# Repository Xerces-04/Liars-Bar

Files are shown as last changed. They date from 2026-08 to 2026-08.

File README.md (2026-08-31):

# Liar's Bar: Tabletop Hardware Edition

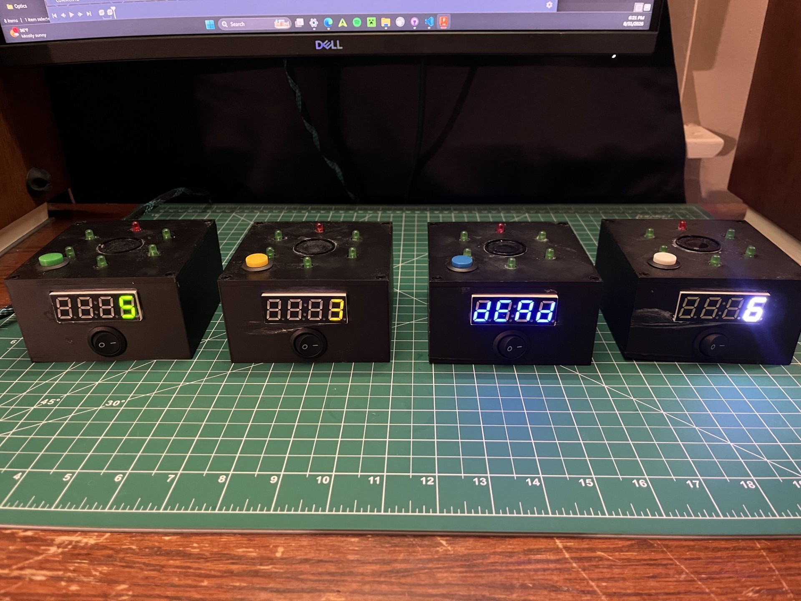
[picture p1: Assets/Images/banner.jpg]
Project Banner


An interactive, embedded implementation of the *Liar's Bar* revolver / Russian Roulette game mechanic built on Arduino. The project features randomized chamber states, dynamic LED indicator animations, synchronized audio cues via a DFPlayer Mini, real-time life tracking on a 7-segment display, and a dedicated 3D-printable square enclosure with heat-set threaded inserts.

---

## Features

* **True-Random Cylinder Spin:** Seeds pseudo-random generation using floating analog noise on pin `A0` combined with a Fisher-Yates array shuffle.
* **Synchronized Audio System:** Multi-channel sound effects driven by the DFPlayer Mini:
  * Cylinder spinning & cocking on startup/reload
  * Hammer cock on trigger pull
  * Dry fire click on safe rounds
  * Gunshot on live rounds
* **Visual Status Indicators:**
  * **TM1637 4-Digit Display:** Tracks remaining chamber counts (`6` down to `1`) and displays a custom `dEAd` segment pattern on elimination.
  * **6-LED Array:** 5 Green LEDs (safe chambers) and 1 Red LED (lethal chamber) with dynamic spinning deceleration sequences.
* **Rugged Enclosure Design:** Two-part square enclosure (base + lid) joined via four M3 heat-set brass inserts, featuring front-facing power and status readouts and top-mounted player controls.

---

## System Architecture & Pinout

```
                           +-------------------+
                           |    Arduino Uno/   |
                           |    Nano (MCU)     |
                           +---------+---------+
                                     |
      +---------------+--------------+--------------+---------------+
      |               |              |              |               |
+-----+-----+   +-----+-----+  +-----+-----+  +-----+-----+   +-----+-----+
|  TM1637   |   | DFPlayer  |  | 6x LED    |  | Fire      |   | Power     |
| 7-Segment |   |   Mini    |  | Array     |  | Pushbutton|   | Rocker    |
| (CLK/DIO) |   | (Software |  | (5G / 1R) |  | (Pullup)  |   | Switch    |
|           |   |  Serial)  |  |           |  |           |   |           |
+-----------+   +-----------+  +-----------+  +-----------+   +-----------+
```

### Pin Assignment Table

| Arduino Pin | Connected Hardware | Signal / Mode | Description |
| :--- | :--- | :--- | :--- |
| **D2** | Green LED 1 (`G1`) | `OUTPUT` | Safe Chamber 1 Indicator |
| **D3** | Green LED 2 (`G2`) | `OUTPUT` | Safe Chamber 2 Indicator |
| **D4** | Green LED 3 (`G3`) | `OUTPUT` | Safe Chamber 3 Indicator |
| **D5** | Green LED 4 (`G4`) | `OUTPUT` | Safe Chamber 4 Indicator |
| **D6** | Green LED 5 (`G5`) | `OUTPUT` | Safe Chamber 5 Indicator |
| **D7** | Red LED 1 (`R1`) | `OUTPUT` | Lethal Chamber Indicator |
| **D8** | TM1637 Display | `OUTPUT` | Display Clock (`CLK`) |
| **D9** | Push Button | `INPUT_PULLUP`| Fire / Trigger / Reset Action |
| **D10** | TM1637 Display | `OUTPUT` | Display Data I/O (`DIO`) |
| **D11** | DFPlayer Mini `RX` | `OUTPUT` (SoftSerial) | Arduino TX → DFPlayer RX (via 1kΩ resistor) |
| **D12** | DFPlayer Mini `TX` | `INPUT` (SoftSerial) | Arduino RX ← DFPlayer TX |
| **A0** | *Unconnected* | `INPUT` | Floating ADC input for random entropy |
| **A1** | DFPlayer Mini `BUSY`| `INPUT` | Audio playback status monitoring |

---

## Custom PCB Design

A custom carrier PCB was designed in KiCad/EasyEDA to eliminate messy point-to-point breadboard wiring, consolidate the pullups and current-limiting resistors, and fit snugly inside the 3D-printed enclosure.

| Schematic View | 3D Board Render |
| :---: | :---: |
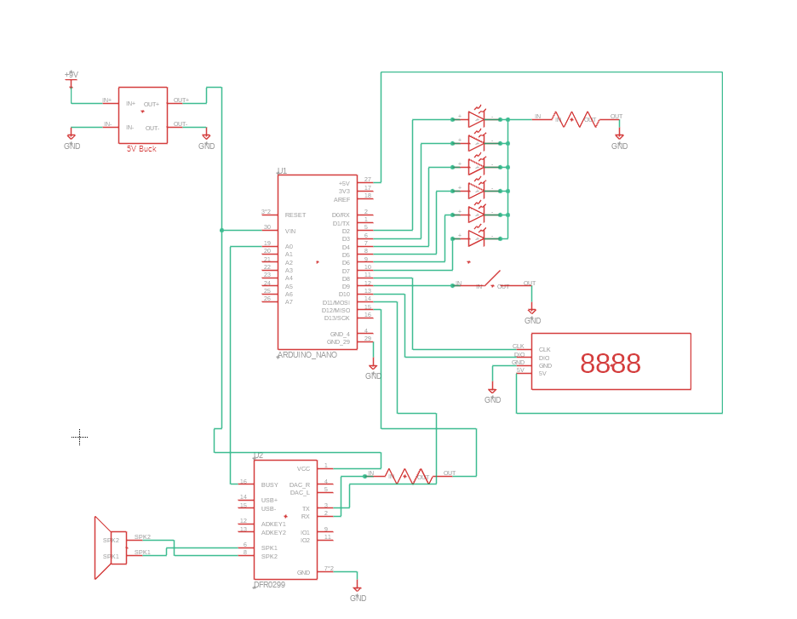
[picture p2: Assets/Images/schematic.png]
PCB Schematic
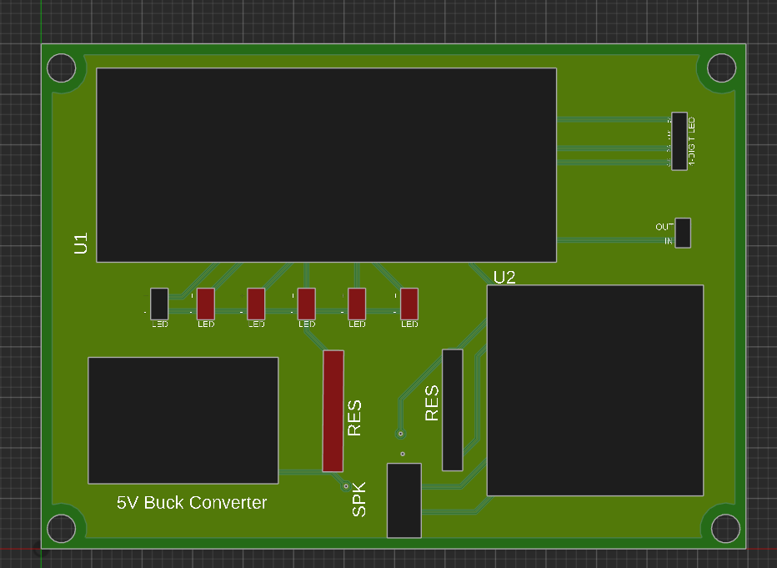
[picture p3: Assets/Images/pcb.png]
PCB 3D Render
|  |  |

### PCB Highlights & Specifications
* **Form Factor:** Custom dual-layer FR-4 board (2-layer, 1.6mm thickness).
* **Socketed Modules:** Direct female header sockets for the **Arduino Nano** and **DFPlayer Mini** to allow easy swapping and reprogramming.
* **Onboard Power Conditioning:** 
  * Integrated bypass capacitors across `VCC`/`GND` rails to prevent audio buzz/pops from the DFPlayer Mini amplifier.
  * Dedicated JST-XH / screw-terminal power input header connected in series with the rocker switch line.
* **Direct Panel Breakouts:** JST-XH connector pads for off-board panel-mounted components (TM1637 Display, Trigger Button, Speaker, and Power Switch).
* **LED Array Layout:** Arranged radially on-board (or via ribbon header to the top lid) with integrated SMD/THT current-limiting resistors.

> Gerber and drill files for PCB manufacturing are available in the [`Gerbers`](Gerbers) directory.

---

## Bill of Materials (BOM)

### Electronics
* 1x Custom Carrier PCB (or standard prototyping perfboard)
* 1x Arduino Nano, Uno, or Pro Micro (ATmega328P based)
* 1x DFPlayer Mini MP3 Module
* 1x MicroSD Card (FAT32 formatted, 32GB max)
* 1x 8Ω 0.5W–3W Dynamic Speaker
* 1x TM1637 4-Digit 7-Segment Display Module
* 5x 5mm Green LEDs
* 1x 5mm Red LED
* 6x 220Ω–330Ω Current-Limiting Resistors (for LEDs)
* 1x 1kΩ Resistor (serial line noise suppression between Arduino D11 & DFPlayer RX)
* 1x SPST Rocker Switch (panel-mount)
* 1x SPST Momentary Push Button (panel-mount, top trigger)
* 1x 9V Battery clip or 5V USB breakout board for power

### Hardware & Enclosure
* 4x M3 Brass Heat-Set Threaded Inserts (e.g., M3 x 4mm or M3 x 5.7mm OD)
* 4x M3 Button Head / Socket Head Machine Screws (M3 x 8mm–12mm)
* 1x 3D-Printed Custom Base Enclosure
* 1x 3D-Printed Custom Top Lid

---

## Enclosure Layout & Mechanical Details

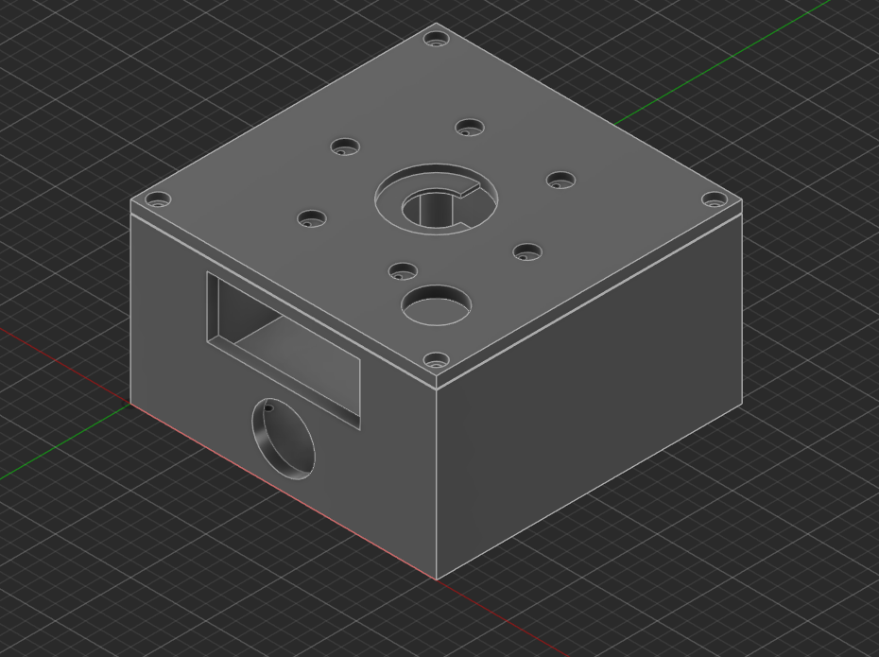
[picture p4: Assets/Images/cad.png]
Enclosure CAD Assembly


* **Front Panel:**
  * Rectangular cutout for the 4-digit TM1637 7-segment display.
  * Rectangular/round cutout for the main SPST rocker power switch.
* **Top Panel (Lid):**
  * Central mounting hole for the trigger push button.
  * 6x Circular bezel holes arranged in an arc/circle for the 5 green LEDs and 1 red LED.
* **Base Mounting:**
  * Four internal corner bosses with pilot holes sized for M3 heat-set inserts.
  * The top lid secures to the base using four countersunk M3 machine screws.

---

## MicroSD Card Setup

1. Format your MicroSD card to **FAT32**.
2. Create a root folder named `01`.
3. Add the following audio files formatted as standard MP3s:

```text
SD_CARD_ROOT/
└── 01/
    ├── 001.mp3  # Spare / reserved
    ├── 002.mp3  # Hammer cock / trigger pull
    ├── 003.mp3  # Dry fire / safe chamber click
    ├── 004.mp3  # Cylinder spin & reload sound
    └── 005.mp3  # Gunshot / lethal round
```

---

## Software Installation & Dependencies

### 1. Required Libraries
Install the following libraries via the Arduino IDE Library Manager (**Sketch → Include Library → Manage Libraries**):
* **`TM1637Display`** by Avishay Orpaz
* **`DFRobotDFPlayerMini`** by DFRobot
* **`SoftwareSerial`** (Included standard with the Arduino AVR core)

### 2. Flashing the Firmware
1. Clone this repository:
   ```bash
   git clone https://github.com/your-username/liars-bar-arduino.git
   ```
2. Open `liars_bar_arduino.ino` in the Arduino IDE.
3. Under **Tools → Board**, select your target board (e.g., **Arduino Nano**).
4. Select the correct **Processor** (e.g., ATmega328P or ATmega328P Old Bootloader) and **Port**.
5. Compile and upload the sketch.

---

## State Machine & Game Logic Flow

```
   [ POWER ON ]
        │
        ▼
   [ State 7: Spin / Init ] ──> Play Sound 004 & Decelerating LED Spin
        │
        ▼ (Press Fire Button)
  ┌─────┴────────────────────────────────────────────────┐
  │ Check randomPins[current_round]                      │
  ├──────────────────────────────┬───────────────────────┤
  │ If Safe Pin (Pins 2-6)       │ If Lethal Pin (Pin 7) │
  ▼                              ▼                       ▼
[ Dry Fire ]                   [ Wet Fire ]
- Decrement lives (6 -> 1)     - Play Sound 002 -> 005
- Play Sound 002 -> 003        - Flash Pin 7 (Red LED)
- Flash corresponding Pin      - Display "dEAd"
- Advance State (8 -> 12)      - Move to State 13 (Game Over)
  │                              │
  └──────────────┬───────────────┘
                 │
                 ▼
         [ State 13: Game Over ]
                 │
                 ▼ (Press Fire Button)
         [ Reset Game ]
         - Re-seed & Fisher-Yates array shuffle
         - Reset display to 6 lives
         - Trigger reload sound & spin sequence
         - Return to State 7
```

---

## Finished Build Gallery

| Assembled Unit | Internal Hardware & PCB Fit |
| :---: | :---: |
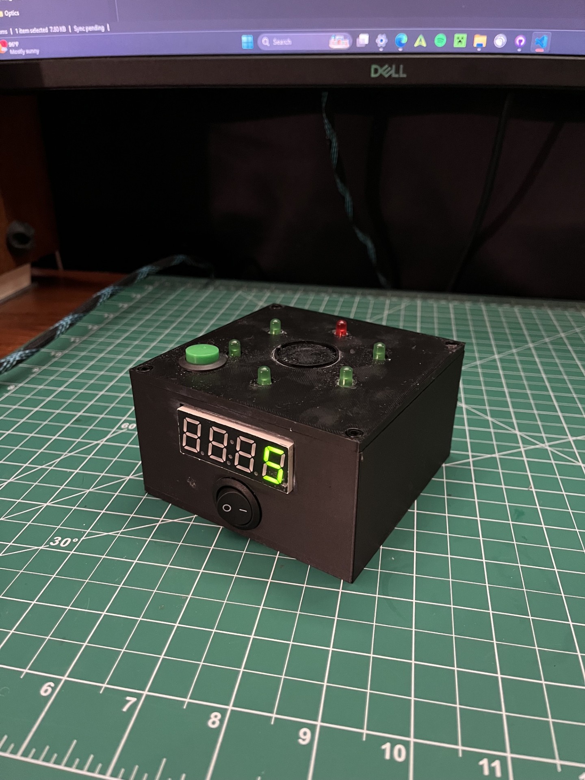
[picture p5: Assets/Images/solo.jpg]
Finished Front View
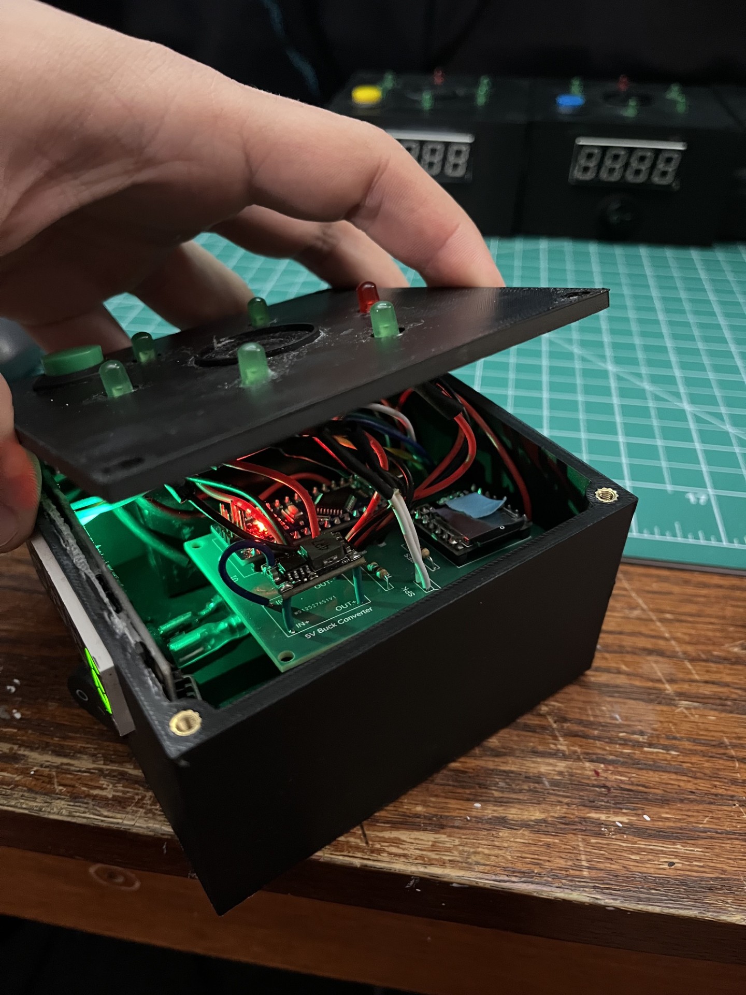
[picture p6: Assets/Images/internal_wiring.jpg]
Internal Wiring Assembly
|  |  |

---

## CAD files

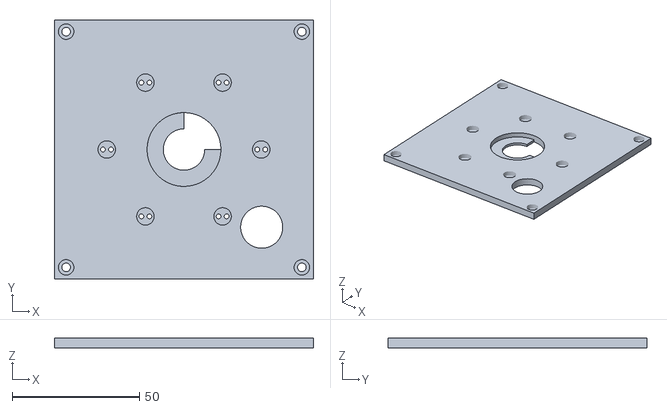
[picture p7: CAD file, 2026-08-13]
Enclosure/Enclosure_Top_Final.stl
101.6 x 101.6 x 3.81

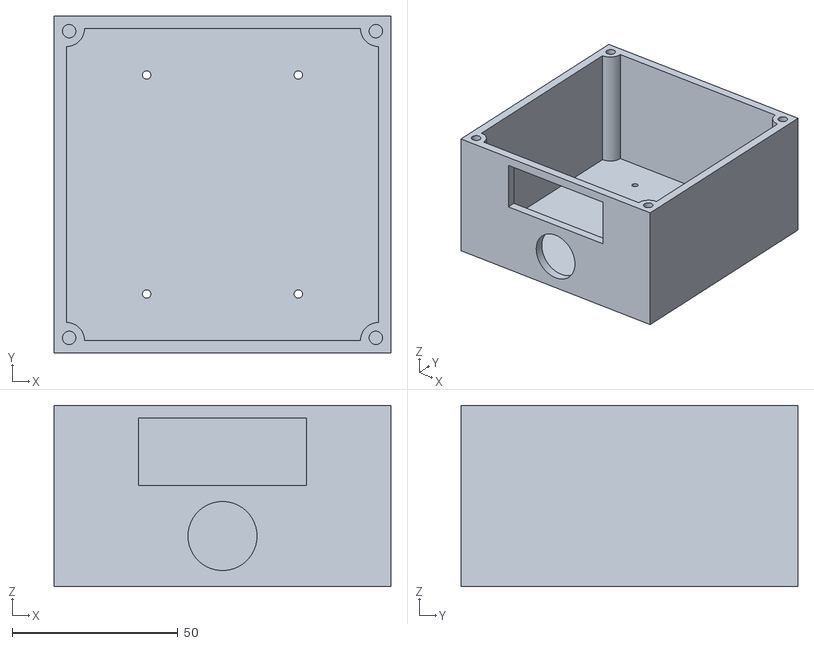
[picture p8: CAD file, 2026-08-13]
Enclosure/Enclosure_Final.stl
101.6 x 101.6 x 54.6

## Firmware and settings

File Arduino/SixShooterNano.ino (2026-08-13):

#include <TM1637Display.h>
#include "DFRobotDFPlayerMini.h"
#include <SoftwareSerial.h>


#define G1 2
#define G2 3
#define G3 4
#define G4 5
#define G5 6
#define R1 7
#define fire 9
#define CLK 8
#define DIO 10
#define Rx 11
#define Tx 12
#define BUSY_PIN A1


//import random
int lives = 6;
int i,j;
int myPins[] = {G1, G2, G3, G4, G5, R1};
int randomPins[] = {G1, G2, G3, G4, G5, R1};
int badPins[] = {0,0,0,0,0,0} ;
int state = 0;
bool displayRunning;
unsigned long startTime;


TM1637Display display(CLK, DIO);
const uint8_t SEG_DEAD[] = {
  SEG_B | SEG_C | SEG_D | SEG_E | SEG_G,          // d
  SEG_A | SEG_D | SEG_E | SEG_F | SEG_G,          // E
  SEG_A | SEG_B | SEG_C | SEG_E | SEG_F | SEG_G,  // A
  SEG_B | SEG_C | SEG_D | SEG_E | SEG_G           // d
};

SoftwareSerial mySoftwareSerial(11, 12); // RX (11), TX (12)
DFRobotDFPlayerMini myDFPlayer;


void setup() {
  delay(5000);
  pinMode(R1, OUTPUT);
  digitalWrite(R1, HIGH);
  delay(2000);
  

  pinMode(G1, OUTPUT);
  pinMode(G2, OUTPUT);
  pinMode(G3, OUTPUT);
  pinMode(G4, OUTPUT);
  pinMode(G5, OUTPUT);
  //pinMode(R1, OUTPUT);
  pinMode(fire, INPUT_PULLUP);
  pinMode(BUSY_PIN, INPUT);

  randomSeed(analogRead(A0));
  randomizeArray(randomPins);

  state = 7;
  display.setBrightness(0x03); // Set brightness (0x00 to 0x0f)
  display.showNumberDec(lives); //start by diplaying the number of lives, 6
  displayRunning = true;

  Serial.begin(9600);
  mySoftwareSerial.begin(9600);

  //digitalWrite(R1, HIGH);

  //delay(1000); // Give the DFPlayer 2 seconds to power up before initializing




  
  while (!myDFPlayer.begin(mySoftwareSerial)) {
    Serial.println("DFPlayer error - check wiring/SD card.");
    delay(1000);
  }
  myDFPlayer.volume(24); // Volume 0 to 30

  //digitalWrite(R1, LOW);
  digitalWrite(R1, LOW);

  lightPinsSpin(); //activate inital spin with reload sound

}

void loop() {

   switch (state) {

    case 7:

      if(digitalRead(fire) == LOW && state == 7){

        addBadPin(randomPins[0]);
        
        if(randomPins[0] == 7){
          wetFire();
          state = 13;
        } else {
          dryFire();
          state = 8;
        }
        lightPins(0);
      }
      break;
    
    case 8:


      if(digitalRead(fire) == LOW && state == 8){
        addBadPin(randomPins[1]);
        if(randomPins[1] == 7){
          wetFire();
          state = 13;

        } else {
          dryFire();
          state = 9;

        }
        lightPins(1);
      }
      break;

    case 9:


      if(digitalRead(fire) == LOW && state == 9){
        addBadPin(randomPins[2]);
        if(randomPins[2] == 7){
          wetFire();
          state = 13;
        } else {
          dryFire();
          state = 10;
        }
        lightPins(2);
      }
      break;

    case 10:


      if(digitalRead(fire) == LOW && state == 10){
        addBadPin(randomPins[3]);
        if(randomPins[3] == 7){
          wetFire();
          state = 13;
        } else {
          dryFire();
          state = 11;
        }
        lightPins(3);
      }
      break;

    case 11:


      if(digitalRead(fire) == LOW && state == 11){
        addBadPin(randomPins[4]);
        if(randomPins[4] == 7){
          wetFire();
          state = 13;
        } else {
          dryFire();
          state = 12;
        }
        lightPins(4);
      }
      break;

    case 12:

      if(digitalRead(fire) == LOW && state == 12){
        addBadPin(randomPins[5]);
        wetFire();
        state = 13;
        lightPins(5);
      }
      break;

    case 13:

      

      if (displayRunning && (millis() - startTime >= 15000))
      {
        display.clear();
        displayRunning = false;
      }
      // Game over sequence
      if(digitalRead(fire) == LOW) {
        resetGame(); 
      }
      break;
  }
}

void addBadPin(int badPin){
  int hold;
  hold = badPin;
  badPin = badPin - 2;
  badPins[badPin] = hold;
}

void lightPins(int j)
{
  digitalWrite(randomPins[j], HIGH);
  delay(1000);
  digitalWrite(randomPins[j], LOW);

}
void lightPinsSpin() {
  triggerSound(4);
  delay(2900);
  int spinDelay = 7; 
  unsigned long startTime = millis(); // Record the start time
  unsigned long duration = 600;      // 3 seconds in milliseconds

  // Keep spinning as long as 3 seconds haven't passed
  while (millis() - startTime < duration) {
    for (int j = 0; j < 6; j++) {
      // Check again inside the loop to ensure we don't start a 
      // new pin cycle if the time has just run out
      if (millis() - startTime >= duration) break;

      digitalWrite(myPins[j], HIGH);
      delay(spinDelay);
      digitalWrite(myPins[j], LOW);

      // Increase delay to simulate slowing down
      // Adjust the '+ 2' to a smaller number if it stops too fast
      spinDelay += 4; 
    }
}

}

void randomizeArray(int orderedPins[6]) {
  // 1. Seed the random generator ONCE at the start of the shuffle
  // We use an unconnected analog pin for floating voltage "noise"
  randomSeed(micros() + analogRead(A0)); 

  // 2. Fisher-Yates Shuffle
  // We start from the end of the array and swap each element with 
  // a random element that comes before it.
  for (int i = 5; i > 0; i--) {
    // Pick a random index from 0 to i
    int j = random(0, i + 1);
    
    // Swap orderedPins[i] with orderedPins[j]
    int temp = orderedPins[i];
    orderedPins[i] = orderedPins[j];
    orderedPins[j] = temp;
  }

  // Optional: Visual feedback that the "gun is loaded"

}



void resetGame() {

  lives = 6;
  for (int k = 0; k < 6; k++) {
    badPins[k] = 0;
  }
  
  // Re-shuffle for the new game
  randomizeArray(randomPins); 

  display.clear();
  display.showNumberDec(6);
  
  // Jump straight to the first trigger pull state
  state = 7; 
  while(digitalRead(fire) == LOW)
  {
    delay(100);

  }
  Serial.println("Gun Reloaded. Ready for Round 1.");

  lightPinsSpin();

  displayRunning = true;
  
}

// In your loop logic, replace playBang() with:
void triggerSound(int fileNumber) {
  myDFPlayer.playFolder(1, fileNumber);
}

void waitForSound() {
  delay(100); // Give the DFPlayer a moment to actually start the file
  while (digitalRead(BUSY_PIN) == LOW) {
    // Do nothing! Just wait for the sound to finish.
  }
  Serial.println("Sound Over");
}

void dryFire()
{
  lives = lives - 1;
  triggerSound(2);
  delay(2500);
  triggerSound(3);
  display.clear();
  display.showNumberDec(lives);
  //waitForSound();
}

void wetFire()
{
  triggerSound(2);
  delay(2500);
  triggerSound(5);
  display.clear();
  display.setSegments(SEG_DEAD);
  startTime = millis();
  //waitForSound();
}

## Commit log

2026-08-13 First Commit
    8-13-2026
    [6Shhot_Schematic.kicad_pcb, 6Shhot_Schematic.kicad_sch, Enclosure.step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]
2026-08-31 Cleanup
    8/31/2026
    [6Shhot_Schematic.kicad_pcb, 6Shhot_Schematic.kicad_sch, Enclosure.step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]
